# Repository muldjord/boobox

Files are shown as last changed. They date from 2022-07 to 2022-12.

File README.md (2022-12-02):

# BooBox
A fun Raspberry Pi Pico W project that combines a few pieces of hardware to create a motion-activated talking skull.

Whenever the motion detector triggers The Pico fetches a sound from the provided TCP server and plays it through the speaker. The jaw matches the audio using a tiny servo that pushes down on a piston that rests on whatever surface the skull is placed on. The skull / Pico W is powered using an ordinary phone charger and a micro USB cable.

I plan on making a more thorough step-by-step explanation on how to built your own BooBox when I get the time. For now, what follows is a quick and dirty walkthrough that should provide all necessary information although in a pretty basic and non-visual way.

_**NOTE!** All sounds added to the BooBox server `data` folder **must** be 11KHz 8 bit unsigned `.wav` files! Due to memory limitations of the Raspberry Pi Pico W the size of each sound file must also be less than 192kb. Files bigger than this will play, but will be cut off._

Here's an example of a BooBox I made looking like the fiendlishly funny _Murray the Demonic Talking Skull_ from the Monkey Island games:

(https://www.youtube.com/watch?v=NpiYJFMU0TQ)

## What you need

### Hardware
* Raspberry Pi Pico W
* Tiny speaker (I use an 8 Ohm, 1 W)
* PIR HC-SR501 motion sensor
* SG90 / Micro Servo 9g servo motor
* MAX98357A class C I2S amplifier module

#### Electronic schematics
Connect everything exactly as seen here. You'll notice that VSYS and GND has many connections. For the VSYS (+5v) you'll need to share one pin from the Pico W. For the GND connections there are several GND spread out over the GPIO pins of the Pico W. You can use any of those except the one marked _AGND_.

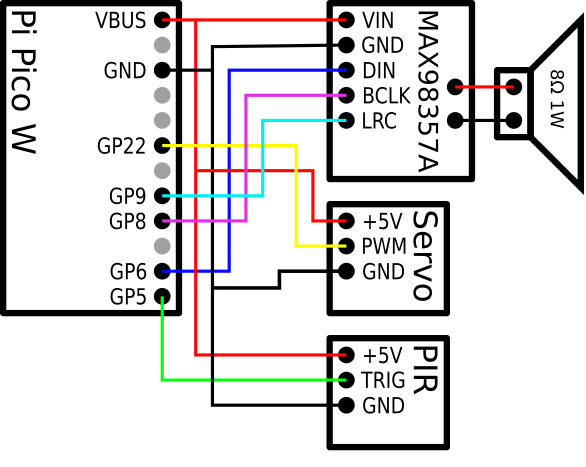
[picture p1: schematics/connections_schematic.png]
Connection schematic


### Software
* The official Pico SDK configured and working (https://github.com/raspberrypi/pico-sdk)
  * Quite easy to get working on a standard Ubuntu machine. Just follow their readme.
* The Qt5 open source SDK
  * On Ubuntu simply run: 'sudo apt-get install qtbase5-dev qtchooser qt5-qmake qtbase5-dev-tools'
* The code from this repository

### 3D models / components
All required 3D models are available in the [3D models](3d_models) subdirectory.

## Building and running
### Server daemon
```
$ cd server
$ qmake
$ make
```
Put your wav files in the `data` directory. Format MUST be mono 11KHz 8 bit unsigned. Now run the server with:
```
$ ./BooBox
```
### Pico client
* Compile the pico_boobox client
```
$ cd client
$ mkdir build
$ cd build
$ cmake -DPICO_BOARD="pico_w" -DWIFI_SSID="SSID" -DWIFI_PASSWORD="PASS" -DTCP_SERVER_IP="SERVERIP" -DTCP_SERVER_PORT="4242" ..
$ make
```
* Hold down the 'reprogram' button on the Pico W and connect the USB cable to the PC, then let go of the button to put the Pico into mass storage mode.
* Drag-n-drop the `pico_boobox.uf2` file onto the Pico mass storage device.

If the server is running, everything is hooked up correctly and you've entered your wifi information and IP, your BooBox should now come to life!

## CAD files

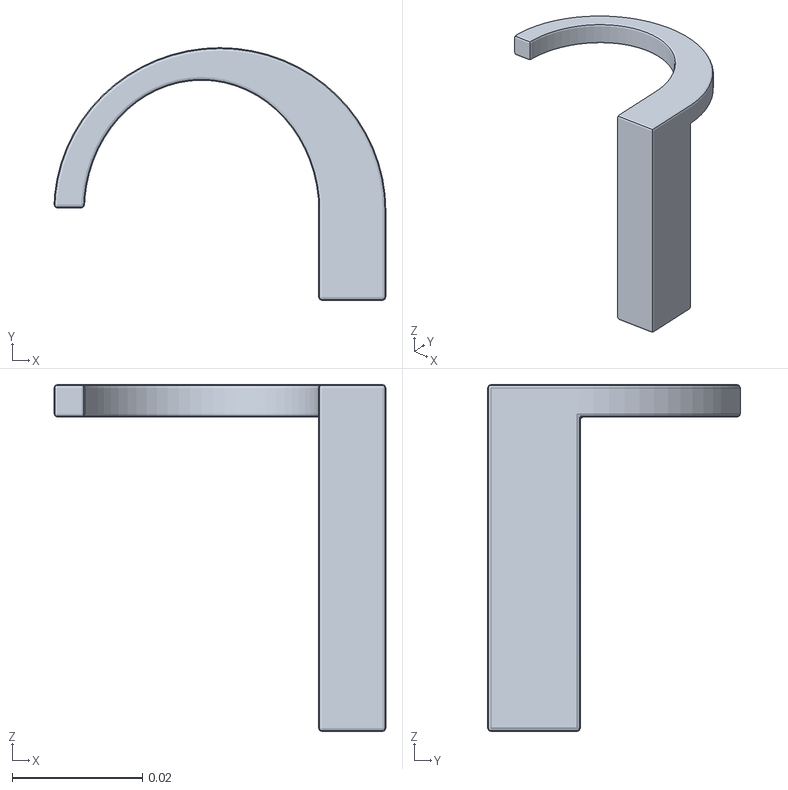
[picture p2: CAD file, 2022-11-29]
3d_models/murray-PIR_pusher.stl
0.0509 x 0.0387 x 0.0532

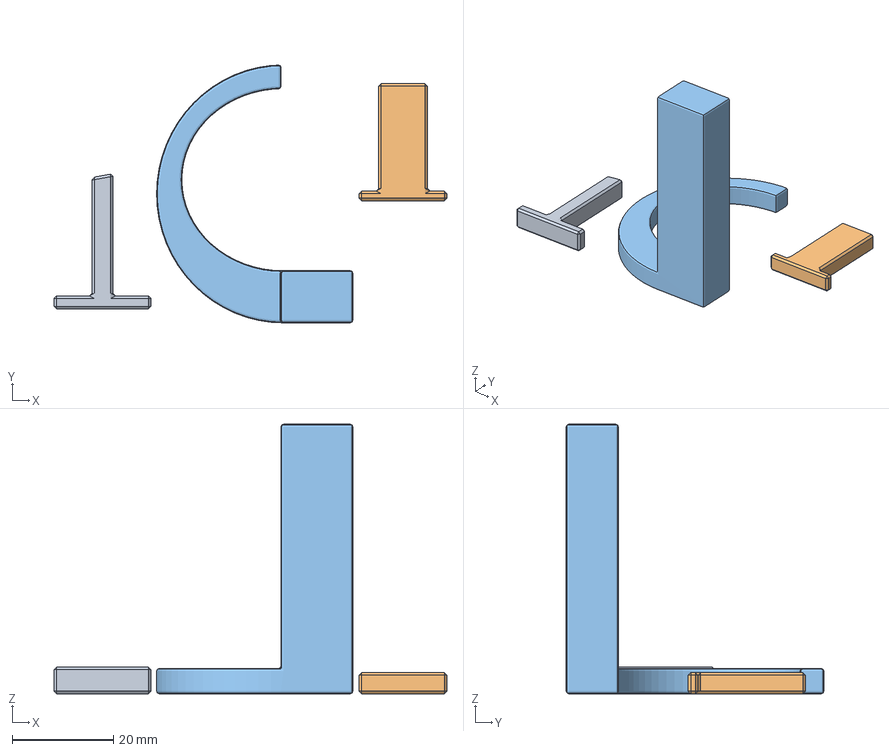
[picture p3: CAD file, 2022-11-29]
3d_models/Murray_helpers.3mf
77.6 x 50.9 x 53.2 mm
murray-Piston.stl
murray-Reprogramming_tool.stl
murray-PIR_pusher.stl

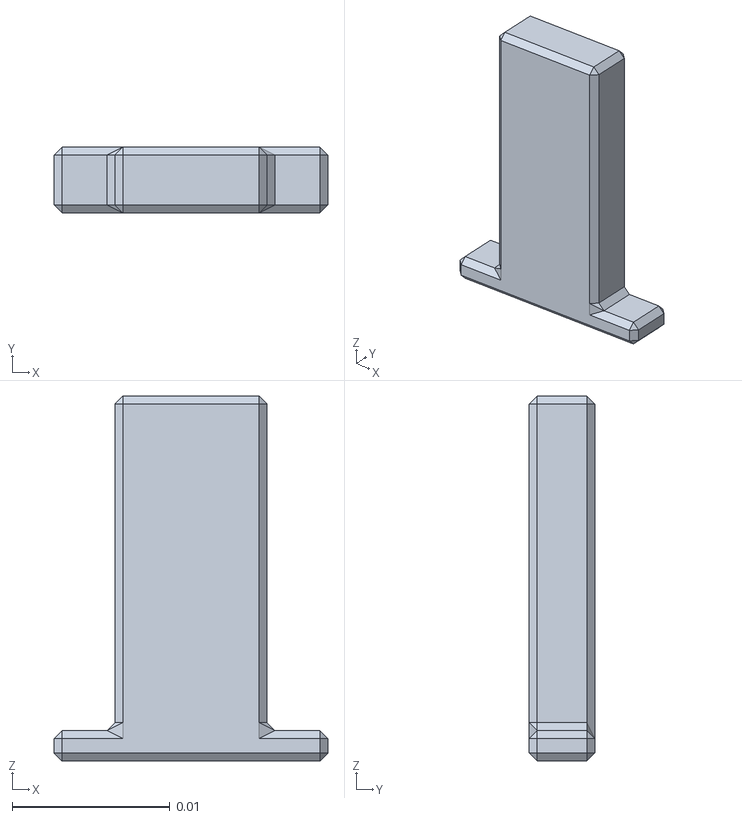
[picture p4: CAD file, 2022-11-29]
3d_models/murray-Reprogramming_tool.stl
0.0173 x 0.00416 x 0.0231

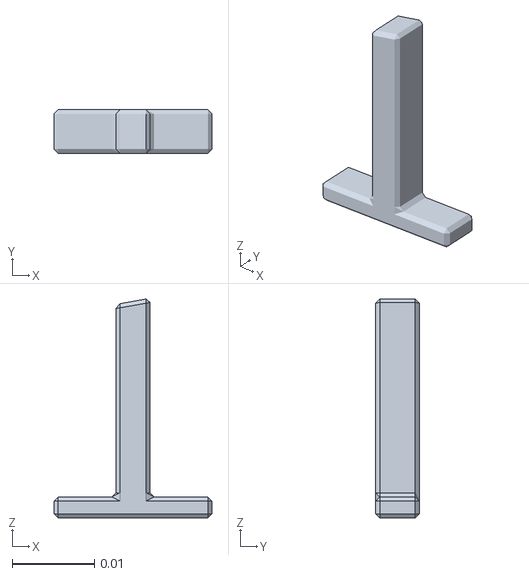
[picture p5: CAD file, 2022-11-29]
3d_models/murray-Piston.stl
0.0192 x 0.00528 x 0.0266

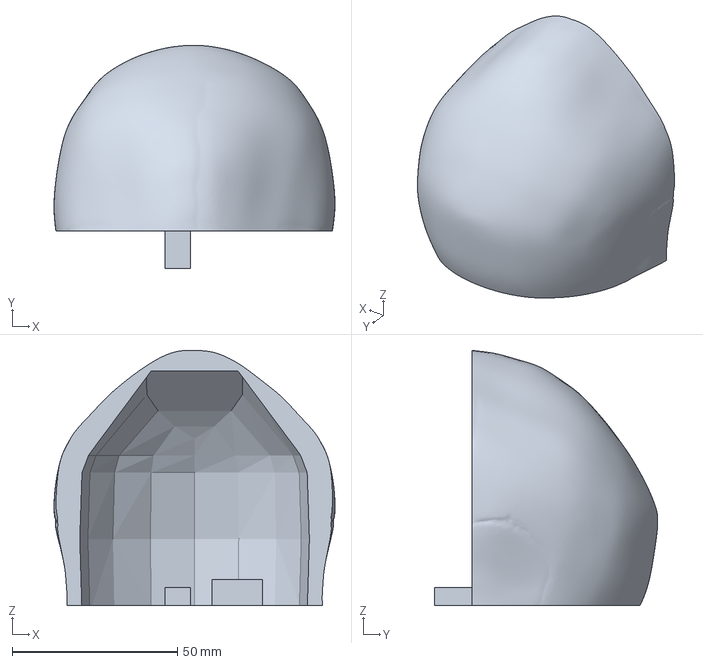
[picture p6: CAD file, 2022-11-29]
3d_models/Murray_back.3mf
85.0 x 67.6 x 77.3 mm

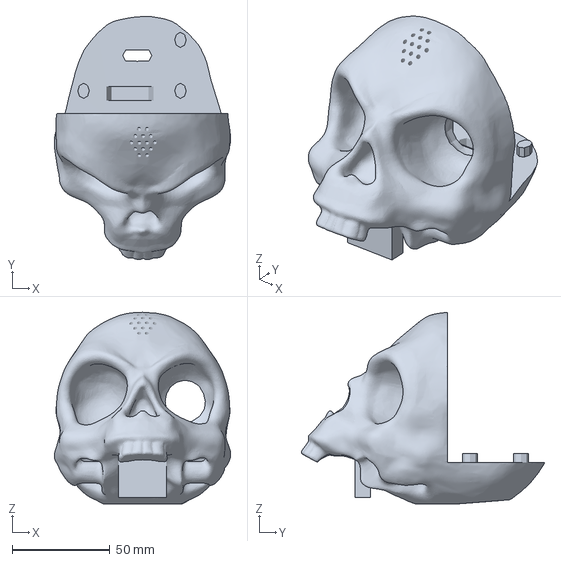
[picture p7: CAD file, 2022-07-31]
3d_models/Murray_front.3mf
90.3 x 124.4 x 98.1 mm

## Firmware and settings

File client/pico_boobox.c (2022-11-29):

#include <math.h>
#include <stdio.h>
#include <string.h>
#include "hardware/clocks.h"
#include "hardware/dma.h"
#include "hardware/irq.h"
#include "hardware/pio.h"
#include "hardware/gpio.h"
#include "hardware/pwm.h"
#include "i2s.h"
#include "pico/stdlib.h"

// wifi
#include "pico/cyw43_arch.h"
#include "lwip/pbuf.h"
#include "lwip/tcp.h"

// TCP socket related
#define BUF_SIZE 192000

typedef struct TCP_CLIENT_T {
  struct tcp_pcb *tcp_pcb;
  ip_addr_t remote_addr;
  uint8_t buffer[BUF_SIZE];
  uint32_t buffer_len;
  uint32_t play_head;
  bool play;
  bool complete;
} TCP_CLIENT_T;

TCP_CLIENT_T *tcpconn = NULL;

static __attribute__((aligned(8))) pio_i2s i2s;

static void dma_i2s_in_handler(void) {
  if(tcpconn->play) {
    if(*(int32_t**)dma_hw->ch[i2s.dma_ch_out_ctrl].read_addr == i2s.output_buffer) {
      for(size_t i = 0; i < AUDIO_BUFFER_FRAMES * 2; i++) {
	i2s.output_buffer[i] = tcpconn->buffer[tcpconn->play_head + (i / 2)]<<23;
      }
    } else {
      for(size_t i = 0; i < AUDIO_BUFFER_FRAMES * 2; i++) {
	(&i2s.output_buffer[STEREO_BUFFER_SIZE])[i] = tcpconn->buffer[tcpconn->play_head + (i / 2)]<<23;
      }
    }
    tcpconn->play_head += AUDIO_BUFFER_FRAMES;
    if(tcpconn->play_head >= tcpconn->buffer_len - (AUDIO_BUFFER_FRAMES * 2)) {
      tcpconn->play = false;
    }
  } else {
    // No sound is playing so just send silence to the DMA buffers
    if(*(int32_t**)dma_hw->ch[i2s.dma_ch_out_ctrl].read_addr == i2s.output_buffer) {
      for(size_t i = 0; i < AUDIO_BUFFER_FRAMES * 2; i++) {
	i2s.output_buffer[i] = 127<<23;
      }
    } else {
      for(size_t i = 0; i < AUDIO_BUFFER_FRAMES * 2; i++) {
	(&i2s.output_buffer[STEREO_BUFFER_SIZE])[i] = 127<<23;
      }
    }
  }

  dma_hw->ints0 = 1u << i2s.dma_ch_out_data;  // clear the IRQ
}

static err_t tcp_client_close(void *arg) {
  TCP_CLIENT_T *tcpconn = (TCP_CLIENT_T*)arg;
  err_t err = ERR_OK;
  if (tcpconn->tcp_pcb != NULL) {
    tcp_arg(tcpconn->tcp_pcb, NULL);
    tcp_recv(tcpconn->tcp_pcb, NULL);
    err = tcp_close(tcpconn->tcp_pcb);
    if (err != ERR_OK) {
      tcp_abort(tcpconn->tcp_pcb);
      err = ERR_ABRT;
    }
    tcpconn->tcp_pcb = NULL;
  }
  tcpconn->complete = true;
  return err;
}

bool wav_init = false;

static err_t tcp_result(void *arg, int status) {
  if (status == 0) {
    // Success
  } else {
    // Failed
  }
  return tcp_client_close(arg);
}

static err_t tcp_client_connected(void *arg, struct tcp_pcb *tpcb, err_t err) {
  if (err != ERR_OK) {
    return tcp_result(arg, err);
  }
  tcp_write(tpcb, "boobox\n", 7, TCP_WRITE_FLAG_COPY);
  return ERR_OK;
}

err_t tcp_client_recv(void *arg, struct tcp_pcb *tpcb, struct pbuf *p, err_t err) {
  TCP_CLIENT_T *tcpconn = (TCP_CLIENT_T*)arg;
  if(p == NULL) { // pbuf is NULL if server closed the connection, meaning transfer was completed
    printf("Wav data recieved: %d bytes\n", tcpconn->buffer_len);
    return tcp_result(arg, err);
  }
  if(p->tot_len > 0) {
    const uint32_t buffer_left = BUF_SIZE - tcpconn->buffer_len;
    //printf("tcpconn->buffer_len: %d, buffer_left: %d, p->tot_len: %d\n", tcpconn->buffer_len, buffer_left, p->tot_len);
    tcpconn->buffer_len += pbuf_copy_partial(p,
					     tcpconn->buffer + tcpconn->buffer_len,
					     p->tot_len > buffer_left ? buffer_left : p->tot_len,
					     0);
    tcp_recved(tpcb, p->tot_len);
  }

  pbuf_free(p);

  return ERR_OK;
}

static bool tcp_client_open(void *arg) {
  TCP_CLIENT_T *tcpconn = (TCP_CLIENT_T*)arg;
  tcpconn->play = false;
  tcpconn->play_head = 0;
  tcpconn->buffer_len = 0;
  tcpconn->complete = false;

  tcpconn->tcp_pcb = tcp_new_ip_type(IP_GET_TYPE(&tcpconn->remote_addr));
  if (!tcpconn->tcp_pcb) {
    return false;
  }

  tcp_arg(tcpconn->tcp_pcb, tcpconn);
  //tcp_sent(tcpconn->tcp_pcb, tcp_client_sent);
  tcp_recv(tcpconn->tcp_pcb, tcp_client_recv);

  cyw43_arch_lwip_begin();
  err_t err = tcp_connect(tcpconn->tcp_pcb, &tcpconn->remote_addr, atoi(TCP_SERVER_PORT), tcp_client_connected);
  cyw43_arch_lwip_end();

  return err == ERR_OK;
}

const uint SERVO_PIN = 22;
float clockDiv = 64;
float wrap = 39062;

void setMillis(int servoPin, float millis)
{
  printf("Setting servo to: %f\n", millis);
  pwm_set_gpio_level(servoPin, (millis/20000.f)*wrap);
}

const uint PIR_PIN = 5;

int main() {
  set_sys_clock_khz(125000, true);
  stdio_init_all();

  // PIR motion sensor init
  gpio_init(PIR_PIN);
  gpio_set_dir(PIR_PIN, GPIO_IN);

  // Servo motor init
  gpio_set_function(SERVO_PIN, GPIO_FUNC_PWM);
  uint slice_num = pwm_gpio_to_slice_num(SERVO_PIN);
  
  pwm_config config = pwm_get_default_config();
  
  uint64_t clockspeed = clock_get_hz(5);
  clockDiv = 64;
  wrap = 39062;
  
  while (clockspeed/clockDiv/50 > 65535 && clockDiv < 256) clockDiv += 64; 
  wrap = clockspeed/clockDiv/50;
  
  pwm_config_set_clkdiv(&config, clockDiv);
  pwm_config_set_wrap(&config, wrap);
  
  pwm_init(slice_num, &config, true);
  
  // Wifi init
  cyw43_arch_init();
  cyw43_arch_enable_sta_mode();
  cyw43_arch_wifi_connect_timeout_ms(WIFI_SSID, WIFI_PASSWORD, CYW43_AUTH_WPA2_AES_PSK, 30000);

  // i2s audio init
  i2s_program_start_synched(pio0, dma_i2s_in_handler, &i2s);

  int state = 0;
  tcpconn = calloc(1, sizeof(TCP_CLIENT_T));
  ip4addr_aton(TCP_SERVER_IP, &tcpconn->remote_addr);
  while(true) {
    //printf("STATE: %d\n", state);
    if(state == 0) {
      if(gpio_get(PIR_PIN)) {
	cyw43_arch_gpio_put(CYW43_WL_GPIO_LED_PIN, 1);
	tcp_client_open(tcpconn);
	state = 1;
      }
    }
    if(state == 1) {
      if(tcpconn->complete) {
	cyw43_arch_gpio_put(CYW43_WL_GPIO_LED_PIN, 0);
	tcpconn->play = true;
	state = 2;
      }
      cyw43_arch_poll();
    }
    if(state == 2) {
      uint32_t servoValue = 0;
      uint32_t servoZero = 1600;
      if(tcpconn->play == false) {
	printf("Closing jaws\n");
	setMillis(SERVO_PIN, servoZero);
	state = 0;
      } else {
	uint32_t lookAhead = 300;
	uint8_t valueSpan = 100;
	for(int i = tcpconn->play_head + lookAhead; i < tcpconn->play_head + lookAhead + valueSpan; ++i) {
	  if(i >= tcpconn->buffer_len) {
	    break;
	  }
	  int32_t curBufferValue = tcpconn->buffer[i];
	  uint32_t curValue = abs(curBufferValue - 128);
	  if(curValue > servoValue) {
	    servoValue = curValue;
	  }
	}
      }
      servoValue *= 2.0;
      if(servoValue > 250) {
	servoValue = 250;
      }
      printf("servoValue: %d\n", servoValue);
      setMillis(SERVO_PIN, servoZero - (servoValue));
    }
    sleep_ms(50);
  }
  free(tcpconn);
  cyw43_arch_deinit();
  return 0;
}

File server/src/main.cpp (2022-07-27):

/* -*- Mode: C++; tab-width: 2; indent-tabs-mode: nil; c-basic-offset: 2 -*- */
/***************************************************************************
 *            main.cpp
 *
 *  Wed Jul 27 09:49:00 CEST 2022
 *  Copyright 2022 Lars Muldjord
 *  muldjordlars@gmail.com
 ****************************************************************************/
/*
 *  This file is part of boobox.
 *
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
 *  You should have received a copy of the GNU General Public License
 *  along with boobox; if not, write to the Free Software
 *  Foundation, Inc., 59 Temple Place, Suite 330, Boston, MA  02111-1307  USA.
 */

#include <QtGlobal>

#include <QCoreApplication>
#include <QDir>
#include <QtDebug>
#include <QCommandLineParser>
#include <QCommandLineOption>
#include <QTimer>

#include "boobox.h"

int main(int argc, char *argv[])
{
  QCoreApplication app(argc, argv);
  app.setApplicationVersion(VERSION);

  QDir::setCurrent(QDir::currentPath());

  QCommandLineParser parser;

  QString headerString = "BooBox v" VERSION;

  parser.setApplicationDescription("BooBox TCP server.");
  parser.addHelpOption();
  parser.addVersionOption();
  QCommandLineOption dOption("d", "Base data path (default is './data')", "PATH", "");
  parser.addOption(dOption);
  QCommandLineOption pOption("p", "Listen port (default is 4242)", "PORT", "");
  parser.addOption(pOption);

  parser.process(app);

  if(parser.isSet("help") || parser.isSet("h")) {
    parser.showHelp();
  } else {
    BooBox *x = new BooBox(parser);
    QObject::connect(x, &BooBox::finished, &app, &QCoreApplication::quit);
    QTimer::singleShot(0, x, SLOT(run()));
  }
  return app.exec();
}

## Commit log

2022-07-31 3D model resources
    [Murray_back.3mf, Murray_back.stl, Murray_front.3mf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]
2022-07-31 Connection schematics
2022-07-31 Added schematic
2022-08-01 Updated to match 3mf
    [Murray_back.stl]
2022-08-01 Moved servo jaw movement code into main
2022-08-07 Now uses GP26 for servo and GP22 for PIR sensor
2022-08-07 Updated pin connections
2022-11-28 Pico Murray client using i2s audio
2022-11-29 Removed old models
    [Murray_back.3mf, Murray_back.stl, Murray_jaw.3mf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]
2022-11-29 Added new 3d models
    [Murray_helpers.3mf, murray-PIR_pusher.stl, murray-Piston.stl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]

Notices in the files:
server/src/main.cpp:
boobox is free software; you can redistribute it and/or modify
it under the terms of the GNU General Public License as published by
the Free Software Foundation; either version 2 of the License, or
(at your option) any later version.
